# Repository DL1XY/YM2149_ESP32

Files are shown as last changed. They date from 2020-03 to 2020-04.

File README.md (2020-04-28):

# Yamaha YM2149 ESP32 Soundmodule

## _ATTENTION_
**_DON'T FLASH THE ESP32 WHILE CONNECTED TO POWERSUPPLY ! THIS COULD DESTROY THE ESP32 ! JUST USE AN USB CABLE !_**

## Abstract
This soundmodule enables YM2149 soundgeneration via a web interface in a dedicated WiFi Network or your existing WLAN. 

The YM2149 is Yamaha's pin- and register compatible version of [General Instrument's AY-3-8910](https://en.wikipedia.org/wiki/General_Instrument_AY-3-8910) which was used in legendary video game consoles and home computers like
- Intellivision
- Vectrex
- Amstrad CPC
- MSX
- later ZX Spectrum

The soundchip is controlled by an [Espressif ESP32](ttps://www.espressif.com/en/products/socs/esp32/overview) which also works as
- Webserver providing HTML/JavaScript documents to control the soundchip via browser
- Application Server providing a REST interface
- clock generator for YM2149
- (WiFi Access Point)

## HW Revision 1.0

### Schematic
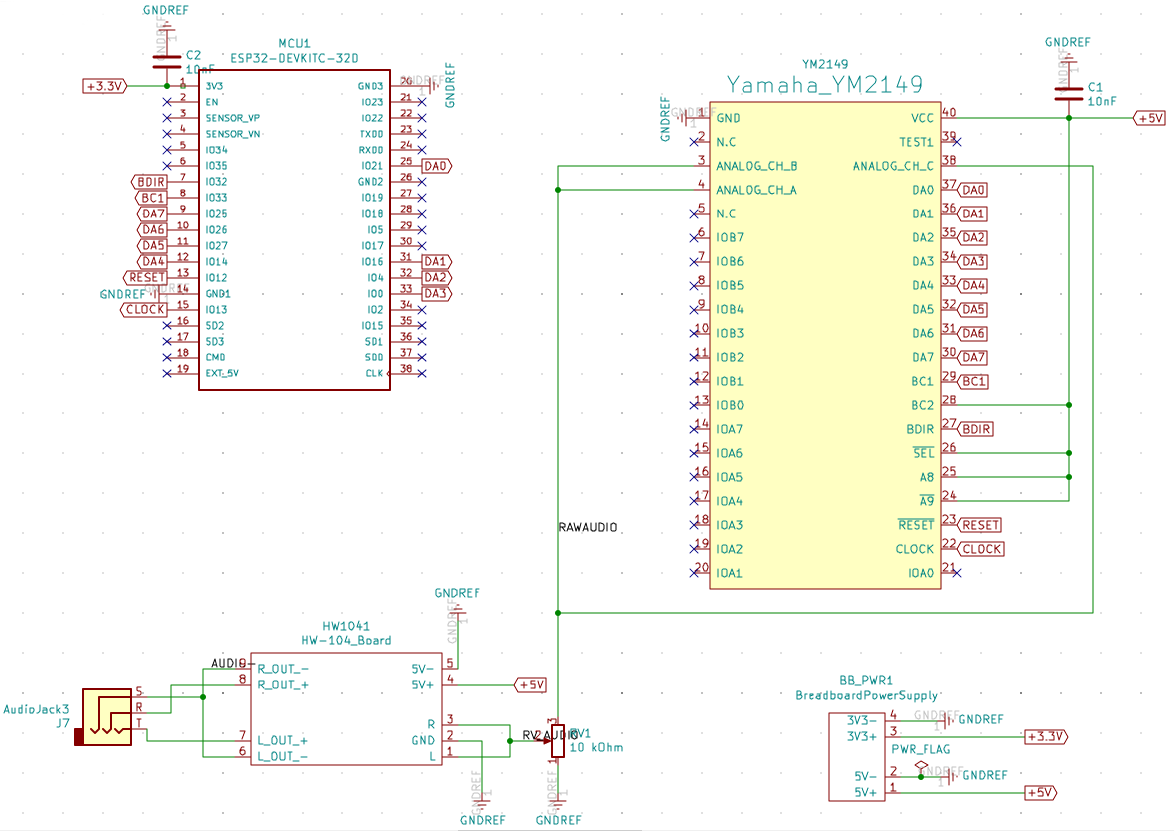
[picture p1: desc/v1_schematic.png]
V1 Schematic
 <!-- .element height="10%" width="10%" -->

### Features
- HW-104 (PAM8403) Amplifier Board
- Breadboard Powersupply(3V3 and 5V) Board 
- ESP32-WROOM Devkit Board
- ALPS RV16 A10K logarithmic potentiometer used
- 6.3mm Audiojack

### Bugs
[ ] Mounting holes at random positions

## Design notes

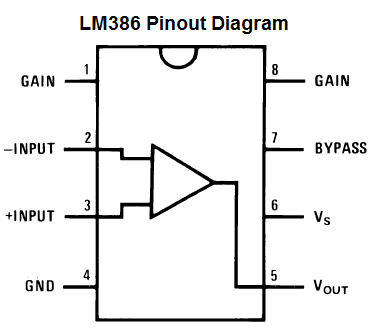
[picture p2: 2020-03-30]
docs/LM386_pinout_diagram.png

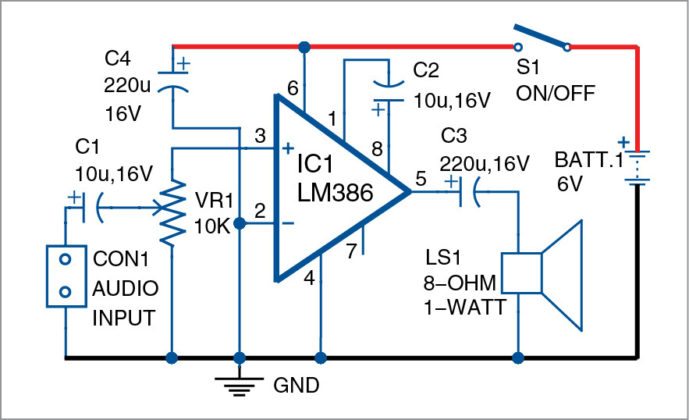
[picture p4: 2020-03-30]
docs/lm386_amp.jpg

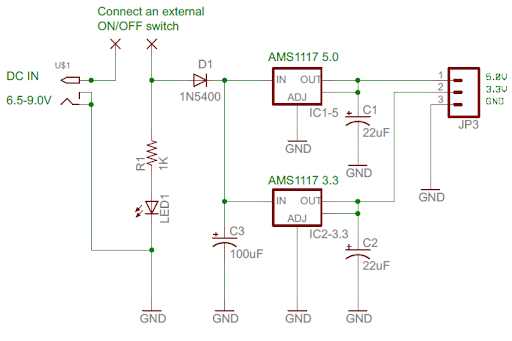
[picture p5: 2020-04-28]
docs/powersupply_5v_3v3.png

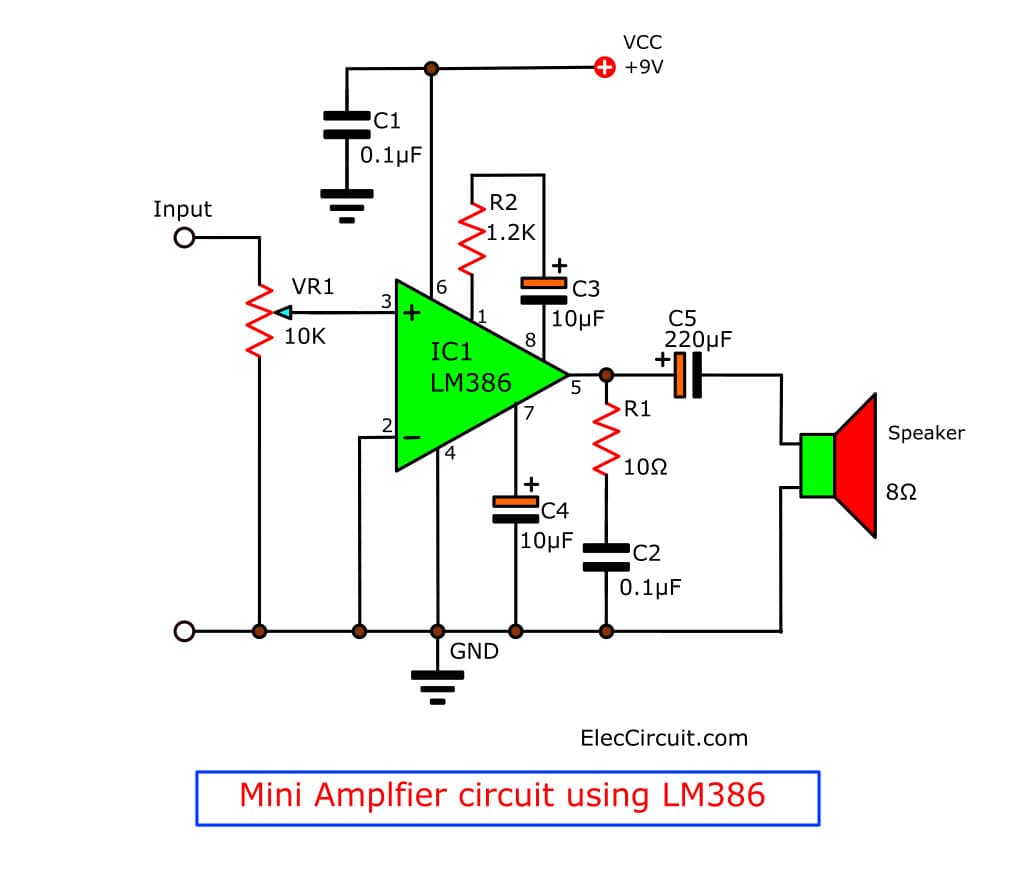
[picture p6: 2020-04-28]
desc/LM386-mini-audio-amplifier-circuit.jpg

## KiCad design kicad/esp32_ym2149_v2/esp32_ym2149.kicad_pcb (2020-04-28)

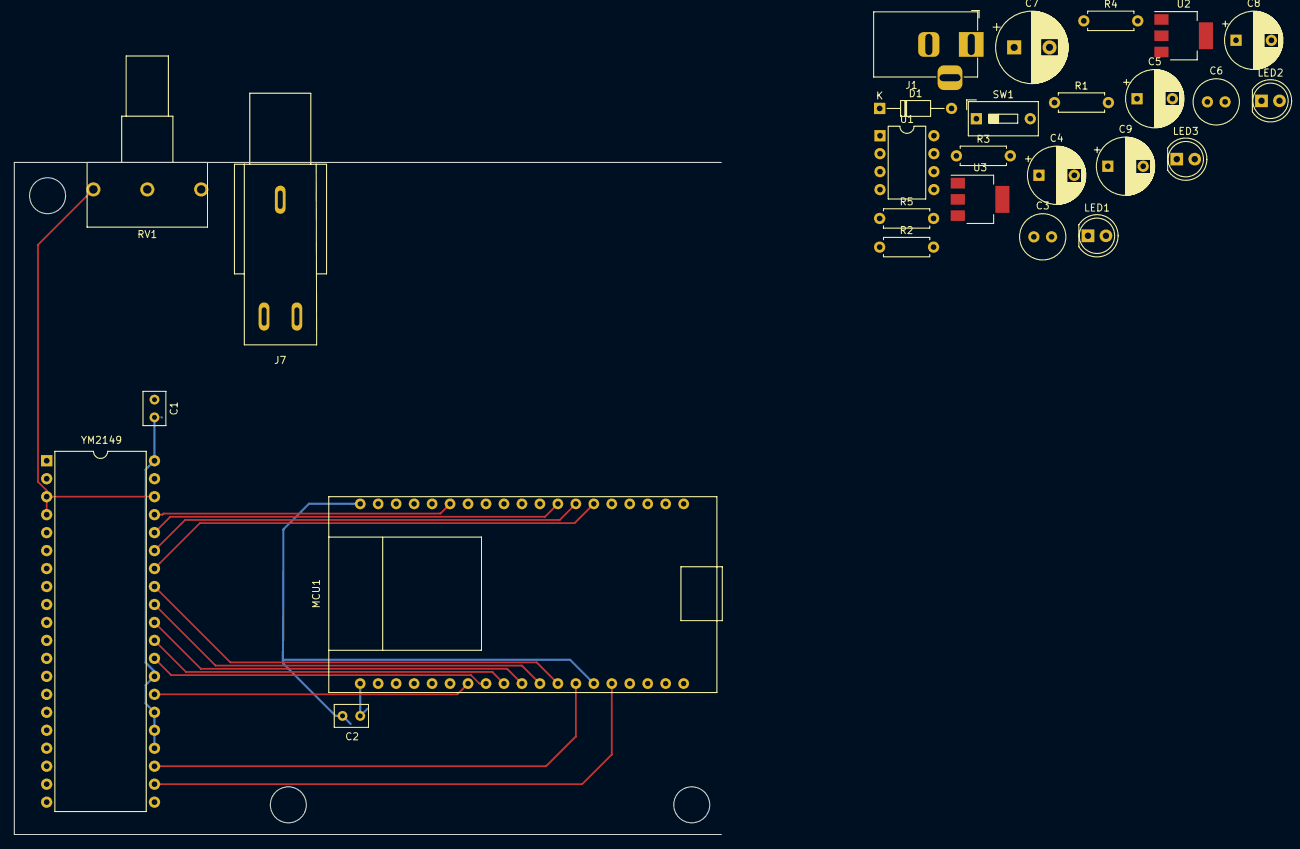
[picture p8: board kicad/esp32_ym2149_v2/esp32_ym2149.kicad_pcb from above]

Board: 2 copper layers, 99.9 x 95.0 mm, 27 parts (0 on the bottom side), 29 nets.

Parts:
C1, C2: 10nF; C_Rect_L4.6mm_W3.0mm_P2.50mm_MKS02_FKP02
C3, C6: 0.1uF; C_Radial_D6.3mm_H5.0mm_P2.50mm
C4, C5: 10uF; CP_Radial_D8.0mm_P5.00mm
C7: 100uF; CP_Radial_D10.0mm_P5.00mm
C8, C9: 22uF; CP_Radial_D8.0mm_P5.00mm
D1: 1N5400; D_DO-35_SOD27_P10.16mm_Horizontal
J1: 9V DC; BarrelJack_Horizontal
J7: AudioJack3; AudioJack 6.5mm
LED1: POWER_LED; LED_D5.0mm
LED2: 3V3_LED; LED_D5.0mm
LED3: 5V_LED; LED_D5.0mm
MCU1: ESP32-DEVKITC-32D; ESP32-WROOM-Devkit
R1, R2: 1.2K; R_Axial_DIN0207_L6.3mm_D2.5mm_P7.62mm_Horizontal
R3: 1k; R_Axial_DIN0207_L6.3mm_D2.5mm_P7.62mm_Horizontal
R4: 520; R_Axial_DIN0207_L6.3mm_D2.5mm_P7.62mm_Horizontal
R5: 220; R_Axial_DIN0207_L6.3mm_D2.5mm_P7.62mm_Horizontal
RV1: 10 kOhm; ALPHA POT 16 RV16
SW1: SW_SPST; SW_DIP_SPSTx01_Slide_9.78x4.72mm_W7.62mm_P2.54mm
U1: LM386; DIP-8_W7.62mm
U2: AMS1117-5.0; SOT-223-3_TabPin2
U3: AMS1117-3.3; SOT-223-3_TabPin2
YM2149: Yamaha_YM2149; DIP-40_W15.24mm

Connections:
+3.3V: C2.2, C9.1, MCU1.1, R5.1, U3.2
+5V: C1.2, C3.2, C8.1, R4.1, U1.6, U2.2, YM2149.24, YM2149.25, YM2149.26, YM2149.28, YM2149.40
/RAWAUDIO: RV1.3, YM2149.3, YM2149.4, YM2149.38
BC1: MCU1.8, YM2149.29
BDIR: MCU1.7, YM2149.27
CLOCK: MCU1.15, YM2149.22
DA0: MCU1.25, YM2149.37
DA1: MCU1.31, YM2149.36
DA2: MCU1.32, YM2149.35
DA3: MCU1.33, YM2149.34
DA4: MCU1.12, YM2149.33
DA5: MCU1.11, YM2149.32
DA6: MCU1.10, YM2149.31
DA7: MCU1.9, YM2149.30
GNDREF: C1.1, C2.1, C3.1, C4.2, C6.2, C7.2, C8.2, C9.2, J1.2, J7.S, LED1.1, LED2.1, LED3.1, MCU1.14, MCU1.20, RV1.1, U1.2, U1.4, U2.1, U3.1, YM2149.1
unnamed: C4.1, U1.7
unnamed: C5.1, R1.2
unnamed: C5.2, U1.8
unnamed: C6.1, R2.2
unnamed: C7.1, D1.1, U2.3, U3.3
unnamed: D1.2, R3.1, SW1.2
unnamed: J1.1, SW1.1
unnamed: J7.R, J7.T, R2.1, U1.5
unnamed: LED1.2, R3.2
unnamed: LED2.2, R5.2
unnamed: LED3.2, R4.2
unnamed: R1.1, U1.1
RESET: MCU1.13, YM2149.23
RV_AUDIO: RV1.2, U1.3

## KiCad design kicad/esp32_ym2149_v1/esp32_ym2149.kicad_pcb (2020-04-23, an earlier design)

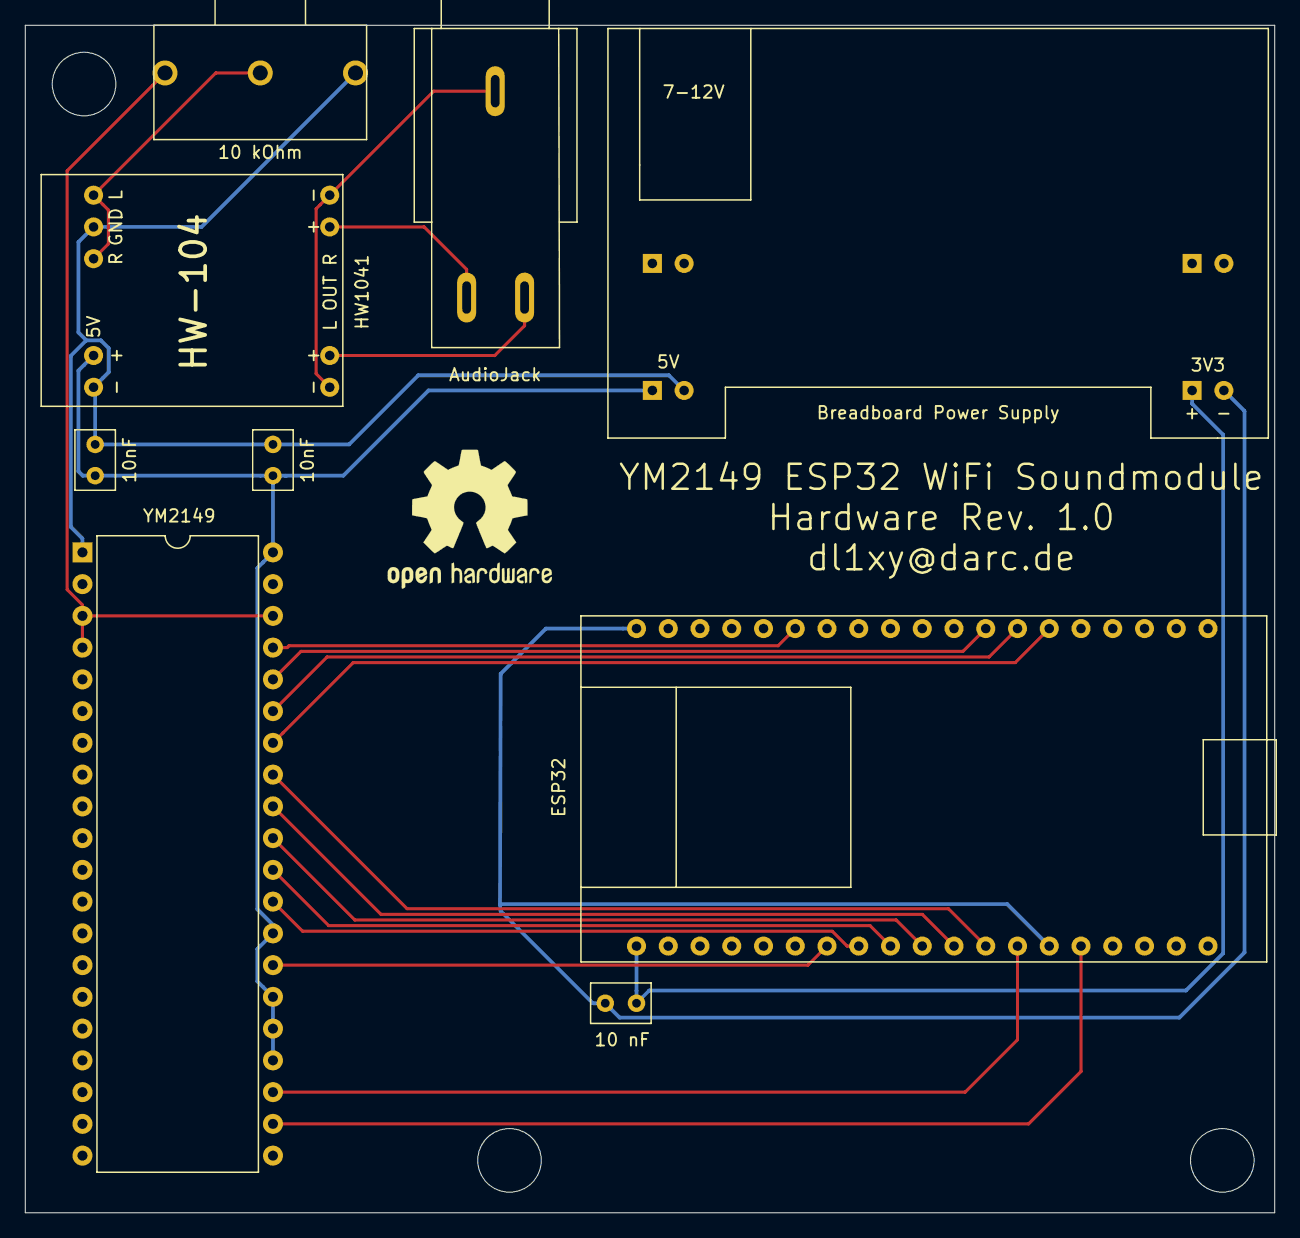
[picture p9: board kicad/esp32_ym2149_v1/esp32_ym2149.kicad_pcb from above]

Board: 2 copper layers, 99.9 x 95.0 mm, 9 parts (0 on the bottom side), 20 nets.

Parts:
10 kOhm: 10 kOhm; ALPHA POT 16 RV16
10 nF, 10nF, 10nF#2: 10nF; C_Rect_L4.6mm_W3.0mm_P2.50mm_MKS02_FKP02
AudioJack: AudioJack3; AudioJack 6.5mm
Breadboard Power Supply: BreadboardPowerSupply; Breadboard_Powersupply_3V3_5V
ESP32: ESP32-DEVKITC-32D; ESP32-WROOM-Devkit
HW1041: HW-104_Board; HW-104 Board
YM2149: Yamaha_YM2149; DIP-40_W15.24mm

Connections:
+3.3V: 10 nF.2, Breadboard Power Supply.3, ESP32.1
+5V: 10nF.2, 10nF#2.2, Breadboard Power Supply.1, HW1041.4, YM2149.24, YM2149.25, YM2149.26, YM2149.28, YM2149.40
BC1: ESP32.8, YM2149.29
BDIR: ESP32.7, YM2149.27
CLOCK: ESP32.15, YM2149.22
DA0: ESP32.25, YM2149.37
DA1: ESP32.31, YM2149.36
DA2: ESP32.32, YM2149.35
DA3: ESP32.33, YM2149.34
DA4: ESP32.12, YM2149.33
DA5: ESP32.11, YM2149.32
DA6: ESP32.10, YM2149.31
DA7: ESP32.9, YM2149.30
GNDREF: 10 kOhm.1, 10 nF.1, 10nF.1, 10nF#2.1, Breadboard Power Supply.2, Breadboard Power Supply.4, ESP32.14, ESP32.20, HW1041.2, HW1041.5, YM2149.1
unnamed: 10 kOhm.2, HW1041.1, HW1041.3
unnamed: AudioJack.S, HW1041.6, HW1041.9
unnamed: AudioJack.T, HW1041.7
unnamed: AudioJack.R, HW1041.8
unnamed: 10 kOhm.3, YM2149.3, YM2149.4, YM2149.38
RESET: ESP32.13, YM2149.23

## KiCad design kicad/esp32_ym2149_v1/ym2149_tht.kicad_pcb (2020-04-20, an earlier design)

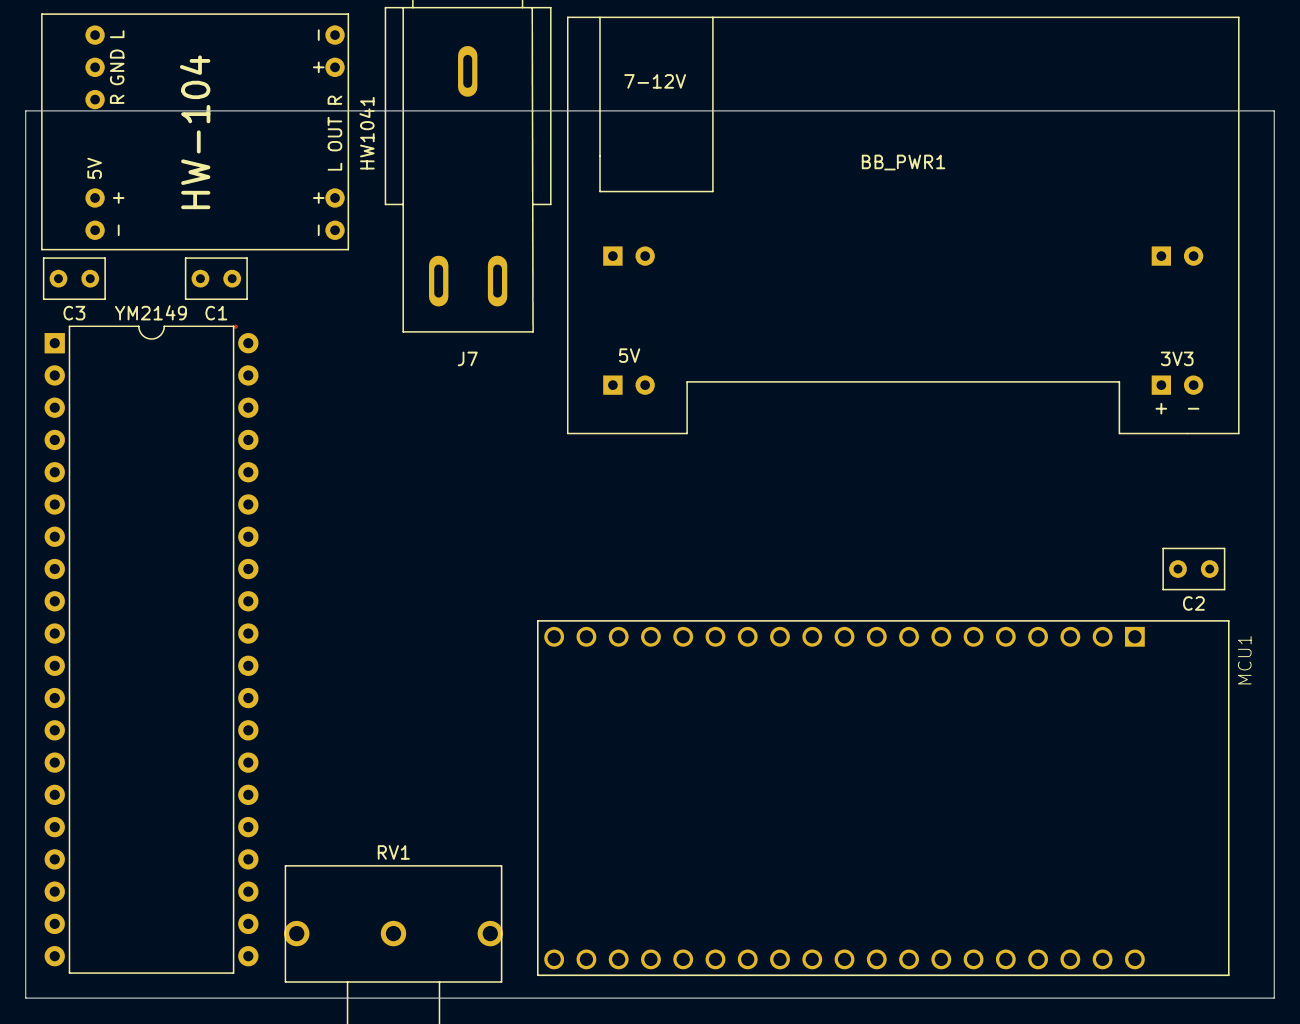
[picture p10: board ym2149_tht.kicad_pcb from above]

Board: 2 copper layers, 98.3 x 69.8 mm, 9 parts (0 on the bottom side), 20 nets.

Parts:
BB_PWR1: BreadboardPowerSupply; Breadboard_Powersupply_3V3_5V
C1, C2, C3: 10nF; C_Rect_L4.6mm_W3.0mm_P2.50mm_MKS02_FKP02
HW1041: HW-104_Board; HW-104 Board
J7: AudioJack3; AudioJack 6.5mm
MCU1: ESP32-DEVKITC-32D; MODULE_ESP32-DEVKITC-32D
RV1: 10 kOhm; ALPHA POT 16 RV16
YM2149: Yamaha_YM2149; DIP-40_W15.24mm

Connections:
+3.3V: BB_PWR1.3, C2.2, MCU1.1
+5V: BB_PWR1.1, C1.2, C3.2, HW1041.4, YM2149.24, YM2149.25, YM2149.26, YM2149.28, YM2149.40
BC1: MCU1.15, YM2149.29
BDIR: MCU1.13, YM2149.27
CLOCK: MCU1.36, YM2149.22
DA0: MCU1.33, YM2149.37
DA1: MCU1.32, YM2149.36
DA2: MCU1.31, YM2149.35
DA3: MCU1.25, YM2149.34
DA4: MCU1.12, YM2149.33
DA5: MCU1.11, YM2149.32
DA6: MCU1.10, YM2149.31
DA7: MCU1.9, YM2149.30
GNDREF: BB_PWR1.2, BB_PWR1.4, C1.1, C2.1, C3.1, HW1041.2, HW1041.5, MCU1.14, MCU1.20, RV1.1, YM2149.1
unnamed: HW1041.1, HW1041.3, RV1.2
unnamed: HW1041.6, HW1041.9, J7.S
unnamed: HW1041.7, J7.T
unnamed: HW1041.8, J7.R
unnamed: RV1.3, YM2149.3, YM2149.4, YM2149.38
RESET: MCU1.35, YM2149.23

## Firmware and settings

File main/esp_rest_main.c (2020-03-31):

/* HTTP Restful API Server Example

   This example code is in the Public Domain (or CC0 licensed, at your option.)

   Unless required by applicable law or agreed to in writing, this
   software is distributed on an "AS IS" BASIS, WITHOUT WARRANTIES OR
   CONDITIONS OF ANY KIND, either express or implied.
*/
#include "sdkconfig.h"
#include "driver/gpio.h"
#include "esp_vfs_semihost.h"
#include "esp_vfs_fat.h"
#include "esp_spiffs.h"
#include "sdmmc_cmd.h"
#include "nvs_flash.h"
#include "esp_netif.h"
#include "esp_event.h"
#include "esp_log.h"
#include "esp_wifi.h"
#include "mdns.h"
#include "lwip/apps/netbiosns.h"
#include "lwip/err.h"
#include "lwip/sys.h"

//#include "protocol_examples_common.h"
#include "secrets.h"
#if CONFIG_EXAMPLE_WEB_DEPLOY_SD
#include "driver/sdmmc_host.h"
#endif
#include "ym2149.h"

#define MDNS_INSTANCE "esp home web server"

static const char *EXAMPLE_TAG = "example";
static const char *WIFI_TAG = "wifi softAP";
esp_err_t YM2149_start_rest_server(const char *base_path);

static void initialise_mdns(void)
{
    mdns_init();
    mdns_hostname_set(CONFIG_EXAMPLE_MDNS_HOST_NAME);
    mdns_instance_name_set(MDNS_INSTANCE);

    mdns_txt_item_t serviceTxtData[] = {
        {"board", "esp32"},
        {"path", "/"}
    };

    ESP_ERROR_CHECK(mdns_service_add("ESP32-WebServer", "_http", "_tcp", 80, serviceTxtData,
                                     sizeof(serviceTxtData) / sizeof(serviceTxtData[0])));
}


#if CONFIG_EXAMPLE_WEB_DEPLOY_SEMIHOST
esp_err_t init_fs(void)
{
    esp_err_t ret = esp_vfs_semihost_register(CONFIG_EXAMPLE_WEB_MOUNT_POINT, CONFIG_EXAMPLE_HOST_PATH_TO_MOUNT);
    if (ret != ESP_OK) {
        ESP_LOGE(EXAMPLE_TAG, "Failed to register semihost driver (%s)!", esp_err_to_name(ret));
        return ESP_FAIL;
    }
    return ESP_OK;
}
#endif

#if CONFIG_EXAMPLE_WEB_DEPLOY_SD
esp_err_t init_fs(void)
{
    sdmmc_host_t host = SDMMC_HOST_DEFAULT();
    sdmmc_slot_config_t slot_config = SDMMC_SLOT_CONFIG_DEFAULT();

    gpio_set_pull_mode(15, GPIO_PULLUP_ONLY); // CMD
    gpio_set_pull_mode(2, GPIO_PULLUP_ONLY);  // D0
    gpio_set_pull_mode(4, GPIO_PULLUP_ONLY);  // D1
    gpio_set_pull_mode(12, GPIO_PULLUP_ONLY); // D2
    gpio_set_pull_mode(13, GPIO_PULLUP_ONLY); // D3

    esp_vfs_fat_sdmmc_mount_config_t mount_config = {
        .format_if_mount_failed = true,
        .max_files = 4,
        .allocation_unit_size = 16 * 1024
    };

    sdmmc_card_t *card;
    esp_err_t ret = esp_vfs_fat_sdmmc_mount(CONFIG_EXAMPLE_WEB_MOUNT_POINT, &host, &slot_config, &mount_config, &card);
    if (ret != ESP_OK) {
        if (ret == ESP_FAIL) {
            ESP_LOGE(EXAMPLE_TAG, "Failed to mount filesystem.");
        } else {
            ESP_LOGE(EXAMPLE_TAG, "Failed to initialize the card (%s)", esp_err_to_name(ret));
        }
        return ESP_FAIL;
    }
    /* print card info if mount successfully */
    sdmmc_card_print_info(stdout, card);
    return ESP_OK;
}
#endif

#if CONFIG_EXAMPLE_WEB_DEPLOY_SF
esp_err_t init_fs(void)
{
    esp_vfs_spiffs_conf_t conf = {
        .base_path = CONFIG_EXAMPLE_WEB_MOUNT_POINT,
        .partition_label = NULL,
        .max_files = 5,
        .format_if_mount_failed = false
    };
    esp_err_t ret = esp_vfs_spiffs_register(&conf);

    if (ret != ESP_OK) {
        if (ret == ESP_FAIL) {
            ESP_LOGE(EXAMPLE_TAG, "Failed to mount or format filesystem");
        } else if (ret == ESP_ERR_NOT_FOUND) {
            ESP_LOGE(EXAMPLE_TAG, "Failed to find SPIFFS partition");
        } else {
            ESP_LOGE(EXAMPLE_TAG, "Failed to initialize SPIFFS (%s)", esp_err_to_name(ret));
        }
        return ESP_FAIL;
    }

    size_t total = 0, used = 0;
    ret = esp_spiffs_info(NULL, &total, &used);
    if (ret != ESP_OK) {
        ESP_LOGE(EXAMPLE_TAG, "Failed to get SPIFFS partition information (%s)", esp_err_to_name(ret));
    } else {
        ESP_LOGI(EXAMPLE_TAG, "Partition size: total: %d, used: %d", total, used);
    }
    return ESP_OK;
}
#endif

static void wifi_event_handler(void* arg, esp_event_base_t event_base,
                                    int32_t event_id, void* event_data)
{
    if (event_id == WIFI_EVENT_AP_STACONNECTED) {
        wifi_event_ap_staconnected_t* event = (wifi_event_ap_staconnected_t*) event_data;
        ESP_LOGI(WIFI_TAG, "station "MACSTR" join, AID=%d",
                 MAC2STR(event->mac), event->aid);
    } else if (event_id == WIFI_EVENT_AP_STADISCONNECTED) {
        wifi_event_ap_stadisconnected_t* event = (wifi_event_ap_stadisconnected_t*) event_data;
        ESP_LOGI(WIFI_TAG, "station "MACSTR" leave, AID=%d",
                 MAC2STR(event->mac), event->aid);
    }
}

void wifi_init_softap(void)
{
    ESP_ERROR_CHECK(esp_netif_init());
    ESP_ERROR_CHECK(esp_event_loop_create_default());
    esp_netif_create_default_wifi_ap();

    wifi_init_config_t cfg = WIFI_INIT_CONFIG_DEFAULT();
    ESP_ERROR_CHECK(esp_wifi_init(&cfg));

    ESP_ERROR_CHECK(esp_event_handler_register(WIFI_EVENT, ESP_EVENT_ANY_ID, &wifi_event_handler, NULL));

    wifi_config_t wifi_config = {
        .ap = {
            .ssid = ESP_WIFI_SSID,
            .ssid_len = strlen(ESP_WIFI_SSID),
            .password = ESP_WIFI_PASS,
            .max_connection = MAX_STA_CONN,
            .authmode = WIFI_AUTH_WPA_WPA2_PSK
        },
    };
    if (strlen(ESP_WIFI_PASS) == 0) {
        wifi_config.ap.authmode = WIFI_AUTH_OPEN;
    }

    ESP_ERROR_CHECK(esp_wifi_set_mode(WIFI_MODE_AP));
    ESP_ERROR_CHECK(esp_wifi_set_config(ESP_IF_WIFI_AP, &wifi_config));
    ESP_ERROR_CHECK(esp_wifi_start());

    ESP_LOGI(WIFI_TAG, "wifi_init_softap finished. SSID:%s password:%s",
             ESP_WIFI_SSID, ESP_WIFI_PASS);
}


void app_main(void)
{
    ESP_ERROR_CHECK(nvs_flash_init());
    //ESP_ERROR_CHECK(esp_netif_init());
    //ESP_ERROR_CHECK(esp_event_loop_create_default());
    wifi_init_softap();
    initialise_mdns();
    netbiosns_init();
    netbiosns_set_name(CONFIG_EXAMPLE_MDNS_HOST_NAME);
    YM2149_init();

    ESP_ERROR_CHECK(init_fs());
    ESP_ERROR_CHECK(YM2149_start_rest_server(CONFIG_EXAMPLE_WEB_MOUNT_POINT));
}

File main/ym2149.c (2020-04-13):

/*
 * ym2149f.c
 *
 *  Created on: 14.03.2020
 *      Author: DL1XY
 */



#include <ym2149.h>
#include "esp_log.h"
#include "driver/ledc.h"
#include "esp_err.h"
#include "driver/periph_ctrl.h"
#include "driver/timer.h"

static const char *TAG = "YM2149";

volatile QueueHandle_t cmd_queue;


ym2149 ym2149_configuration;
ym219_register ym219_register_status;
ym2149_command current_command;
volatile uint8_t currentCmdState;
volatile  uint8_t lastCmdState;

portMUX_TYPE timerMux = portMUX_INITIALIZER_UNLOCKED;
static intr_handle_t s_timer_handle;

void YM2149_init()
{
	 ESP_LOGE(TAG, "Init YM2149");

	 // Init Command Queue
	 cmd_queue = xQueueCreate (16, sizeof (struct ym2149_command));
	 currentCmdState = YM2149_COMMAND_STATE_IDLE;

	 gpio_config_t io_conf;
	 //disable interrupt
	 io_conf.intr_type = GPIO_PIN_INTR_DISABLE;
	 //set as output mode
	 io_conf.mode = GPIO_MODE_OUTPUT;
	 //bit mask of the pins that you want to set,e.g.GPIO18/19
	 io_conf.pin_bit_mask =
			 ((1ULL<<YM2149_RESET_GPIO)	|
			 (1ULL<<YM2149_CLOCK_GPIO) 	|
			 (1ULL<<YM2149_BC1_GPIO)	|
			 (1ULL<<YM2149_BCDIR_GPIO)	|
			 (1ULL<<YM2149_DA0_GPIO)	|
			 (1ULL<<YM2149_DA1_GPIO)	|
		 	 (1ULL<<YM2149_DA2_GPIO)	|
		 	 (1ULL<<YM2149_DA3_GPIO)	|
		 	 (1ULL<<YM2149_DA4_GPIO)	|
		 	 (1ULL<<YM2149_DA5_GPIO)	|
		 	 (1ULL<<YM2149_DA6_GPIO)	|
		 	 (1ULL<<YM2149_DA7_GPIO));
	 //disable pull-down mode
	 io_conf.pull_down_en = 0;
	 //disable pull-up mode
	 io_conf.pull_up_en = 0;
	 //configure GPIO with the given settings
	 gpio_config(&io_conf);


	 // Set GPIO defaults
	 gpio_set_level(YM2149_BC1_GPIO, 0);
	 gpio_set_level(YM2149_BCDIR_GPIO, 0);
	 gpio_set_level(YM2149_RESET_GPIO, 0);

	 gpio_set_level(YM2149_DA0_GPIO, 0);
	 gpio_set_level(YM2149_DA1_GPIO, 0);
	 gpio_set_level(YM2149_DA2_GPIO, 0);
	 gpio_set_level(YM2149_DA3_GPIO, 0);
	 gpio_set_level(YM2149_DA4_GPIO, 0);
	 gpio_set_level(YM2149_DA5_GPIO, 0);
	 gpio_set_level(YM2149_DA6_GPIO, 0);
	 gpio_set_level(YM2149_DA7_GPIO, 0);


	 // Init PWM clock
	 YM2149_init_pwm();
	 YM2149_init_timer_parameter(100);

}


void YM2149_init_pwm()
{
	ESP_LOGE(TAG, "Init YM2149 PWM");
	ledc_timer_config_t ledc_timer = {

		.speed_mode = LEDC_HIGH_SPEED_MODE,
		.timer_num  = LEDC_TIMER_0,
		.bit_num    = 2,
		.freq_hz    = 1000000
	};

	ledc_channel_config_t ledc_channel = {
		.channel    = LEDC_CHANNEL_0,
		.gpio_num   = 15,
		.speed_mode = LEDC_HIGH_SPEED_MODE,
		.timer_sel  = LEDC_TIMER_0,
		.duty       = 2
	};

	ledc_timer_config(&ledc_timer);
	ledc_channel_config(&ledc_channel);
}


void YM2149_init_timer_parameter(int timer_period_us)
{
	 timer_config_t config = {
	            .alarm_en = true,				//Alarm Enable
	            .counter_en = false,			//If the counter is enabled it will start incrementing / decrementing immediately after calling timer_init()
	            .intr_type = TIMER_INTR_LEVEL,	//Is interrupt is triggered on timer’s alarm (timer_intr_mode_t)
	            .counter_dir = TIMER_COUNT_UP,	//Does counter increment or decrement (timer_count_dir_t)
	            .auto_reload = true,			//If counter should auto_reload a specific initial value on the timer’s alarm, or continue incrementing or decrementing.
	            .divider = 80   				//Divisor of the incoming 80 MHz (12.5nS) APB_CLK clock. E.g. 80 = 1uS per timer tick
	    };

	timer_init(TIMER_GROUP_0, TIMER_0, &config);
	timer_set_counter_value(TIMER_GROUP_0, TIMER_0, 0);
	timer_set_alarm_value(TIMER_GROUP_0, TIMER_0, timer_period_us);
	timer_enable_intr(TIMER_GROUP_0, TIMER_0);
	timer_isr_register(TIMER_GROUP_0, TIMER_0, &YM2149_cmdHandler, NULL, 0, &s_timer_handle);

	timer_start(TIMER_GROUP_0, TIMER_0);
}

void IRAM_ATTR YM2149_cmdHandler(void *pvParameter)
{
	TIMERG0.int_clr_timers.t0 = 1;
	TIMERG0.hw_timer[0].config.alarm_en = 1;

	switch (currentCmdState)
	{
		case YM2149_COMMAND_STATE_INIT:
		{
			gpio_set_level(YM2149_BC1_GPIO, 0);
			gpio_set_level(YM2149_BCDIR_GPIO, 0);
			gpio_set_level(YM2149_RESET_GPIO, 0);
			lastCmdState = currentCmdState;
			currentCmdState = YM2149_COMMAND_STATE_IDLE;

		}
			break;
		case YM2149_COMMAND_STATE_IDLE:
		{
			gpio_set_level(YM2149_BC1_GPIO, 0);
			gpio_set_level(YM2149_BCDIR_GPIO, 0);
			lastCmdState = currentCmdState;
			if (uxQueueMessagesWaiting(cmd_queue) > 0)
			{
				xQueueReceiveFromISR (cmd_queue, &current_command, 0 );
				currentCmdState = YM2149_COMMAND_STATE_ADDR_MODE;
			}
		}
		break;
		case YM2149_COMMAND_STATE_ADDR_MODE:
		{
			ets_printf("CMD_ADDR\n");

			// set DATA pins
			gpio_set_level(YM2149_DA0_GPIO, (current_command.register_addr & (1 << 0)));
			gpio_set_level(YM2149_DA1_GPIO, (current_command.register_addr & (1 << 1)));
			gpio_set_level(YM2149_DA2_GPIO, (current_command.register_addr & (1 << 2)));
			gpio_set_level(YM2149_DA3_GPIO, (current_command.register_addr & (1 << 3)));
			gpio_set_level(YM2149_DA4_GPIO, 0);
			gpio_set_level(YM2149_DA5_GPIO, 0);
			gpio_set_level(YM2149_DA6_GPIO, 0);
			gpio_set_level(YM2149_DA7_GPIO, 0);

			// trigger ADDR mode
			gpio_set_level(YM2149_BC1_GPIO, 1);
			gpio_set_level(YM2149_BCDIR_GPIO, 1);
			lastCmdState = currentCmdState;
			currentCmdState = YM2149_COMMAND_STATE_WRITE_MODE;
		}
		break;
		case YM2149_COMMAND_STATE_WRITE_MODE:
		{
			ets_printf("CMD_WRITE\n");

			// set DATA pins
			gpio_set_level(YM2149_DA0_GPIO, (current_command.register_value & (1 << 0)));
			gpio_set_level(YM2149_DA1_GPIO, (current_command.register_value & (1 << 1)));
			gpio_set_level(YM2149_DA2_GPIO, (current_command.register_value & (1 << 2)));
			gpio_set_level(YM2149_DA3_GPIO, (current_command.register_value & (1 << 3)));
			gpio_set_level(YM2149_DA4_GPIO, (current_command.register_value & (1 << 4)));
			gpio_set_level(YM2149_DA5_GPIO, (current_command.register_value & (1 << 5)));
			gpio_set_level(YM2149_DA6_GPIO, (current_command.register_value & (1 << 6)));
			gpio_set_level(YM2149_DA7_GPIO, (current_command.register_value & (1 << 7)));

			// trigger WRITE REG
			gpio_set_level(YM2149_BC1_GPIO, 0);
			gpio_set_level(YM2149_BCDIR_GPIO, 1);

			lastCmdState = currentCmdState;
			currentCmdState = YM2149_COMMAND_STATE_IDLE;
		}
		break;
		case YM2149_COMMAND_STATE_CLEANUP:
		{
			// TODO
		}
		break;
		case YM2149_COMMAND_STATE_RESET:
		{
			gpio_set_level(YM2149_RESET_GPIO, 0);
			xQueueReset(cmd_queue);
			lastCmdState = currentCmdState;
			currentCmdState = YM2149_COMMAND_STATE_INIT;
		}
		break;
	}
}


void YM2149_reset()
{
	//currentCmdState = YM2149_COMMAND_STATE_RESET;
}
void YM2149_playChannel (uint8_t* channel)
{
	ESP_LOGE(TAG, "playChannel(%d)", *channel);
	uint8_t full= 0xff;
	YM2149_setChannelLevel(channel, &full);
}

void YM2149_stopChannel (uint8_t* channel)
{
	ESP_LOGE(TAG, "stopChannel(%d)", *channel);
	YM2149_setChannelLevel(channel, 0);
}
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

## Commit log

2020-03-17 init commit
    [partitions_example.csv]
2020-03-21 Fritzing added !
    [esp32_sndchip_ym2149.fzz]
2020-03-26 small fixes, more logs added
    [ym2149.c, ym2149.h]
2020-03-27 sizeof struct bugfix, cleanup
    [ym2149.c, ym2149.h]
2020-03-27 timer isr fixed
2020-03-28 js fix, cleanup, debug msgs added
    [ym2149.c, ym2149.h]
2020-03-28 KiCAD files added
    [esp32_ym2149.kicad_pcb, esp32_ym2149.sch]
2020-03-29 kicad schema modified
    [esp32_ym2149.sch]
2020-03-29 power supply and audio amp added
    [esp32_ym2149.sch]
2020-03-30 netlist 1st draft added
    [esp32_ym2149.kicad_pcb, esp32_ym2149.sch]
2020-03-31 pcb draft extended
    [esp32_ym2149.sch]
2020-03-31 some minor changes, cleanup
    [esp32_sndchip_ym2149.fzz, esp32_ym2149.kicad_pcb]
2020-04-05 some layout changes
    [esp32_ym2149.kicad_pcb, esp32_ym2149.sch]
2020-04-20 new symbols and footprints added
    [esp32_ym2149.kicad_pcb, esp32_ym2149.sch]
2020-04-21 layout changes
    [esp32_ym2149.kicad_pcb, esp32_ym2149.sch, ym2149_tht.kicad_pcb]
2020-04-23 README modified, Gerber files added, PCB modified
    [esp32_ym2149-B_Cu.gbr, esp32_ym2149-B_Mask.gbr, esp32_ym2149-B_Paste.gbr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]
2020-04-28 folder renamed, v2 folder created
    [esp32_ym2149-B_Cu.gbr, esp32_ym2149-B_Mask.gbr, esp32_ym2149-B_Paste.gbr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]
2020-04-28 README modified, schematic PNG added
    [esp32_ym2149.sch]
2020-04-28 v2 started, docs added, cleanup
    [esp32_ym2149-B_Cu.gbr, esp32_ym2149-B_Mask.gbr, esp32_ym2149-B_Paste.gbr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]
2020-05-01 pcb modified, wifi jumper added
    [esp32_ym2149.kicad_pcb, esp32_ym2149.sch]
